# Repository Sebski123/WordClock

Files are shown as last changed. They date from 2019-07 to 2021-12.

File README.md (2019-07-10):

Wordclock
=========

Instructables: http://www.instructables.com/id/wordclock/

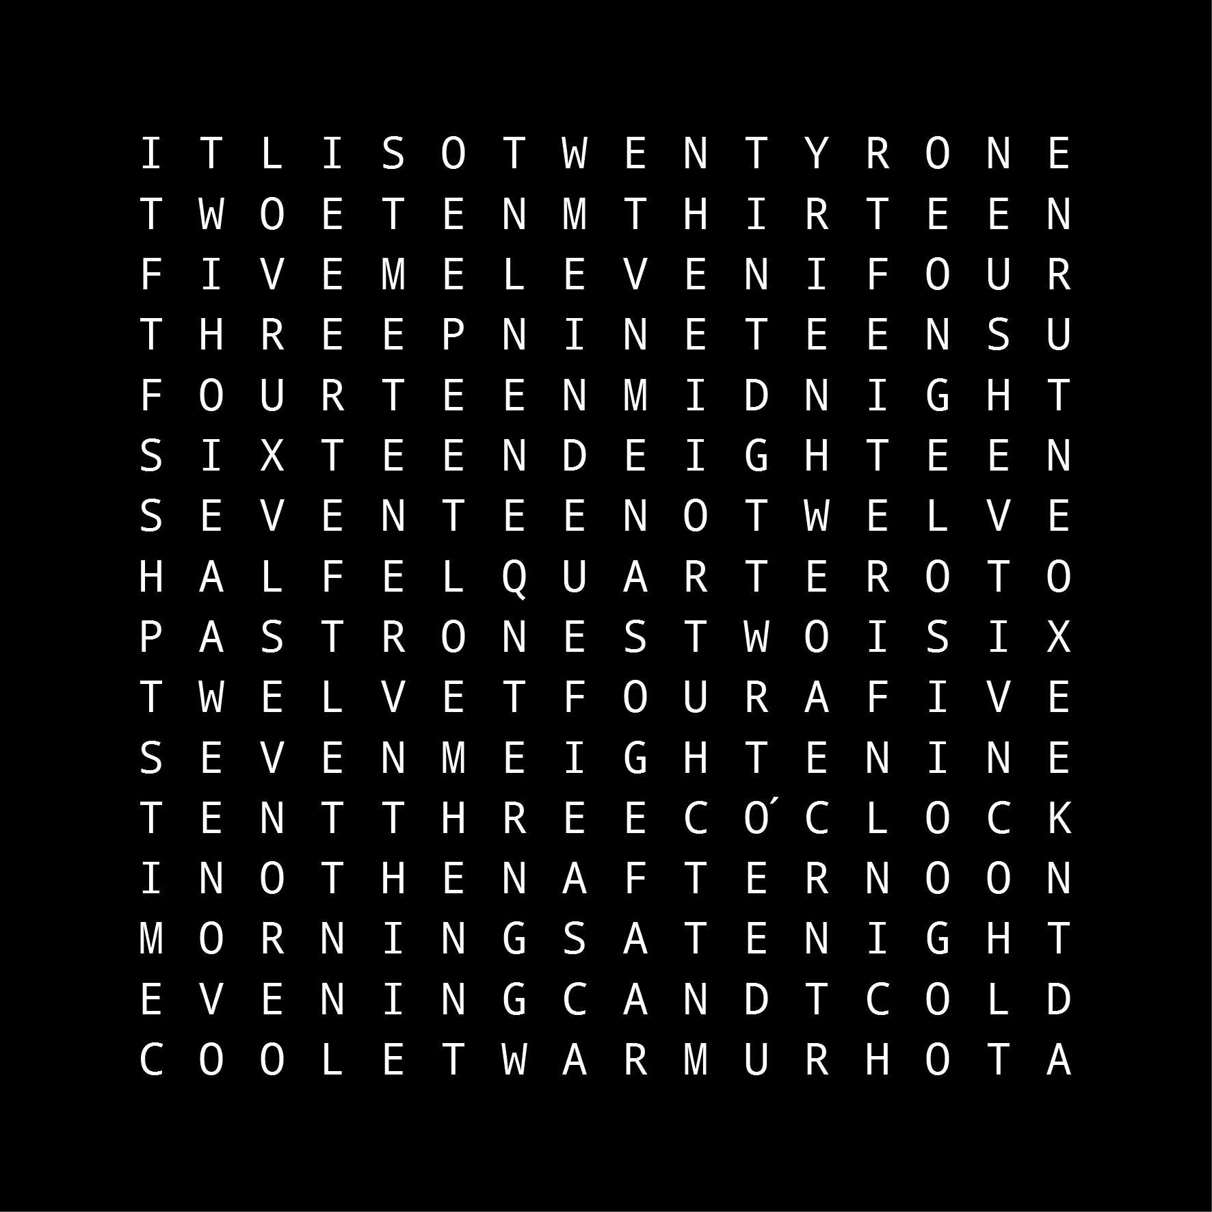
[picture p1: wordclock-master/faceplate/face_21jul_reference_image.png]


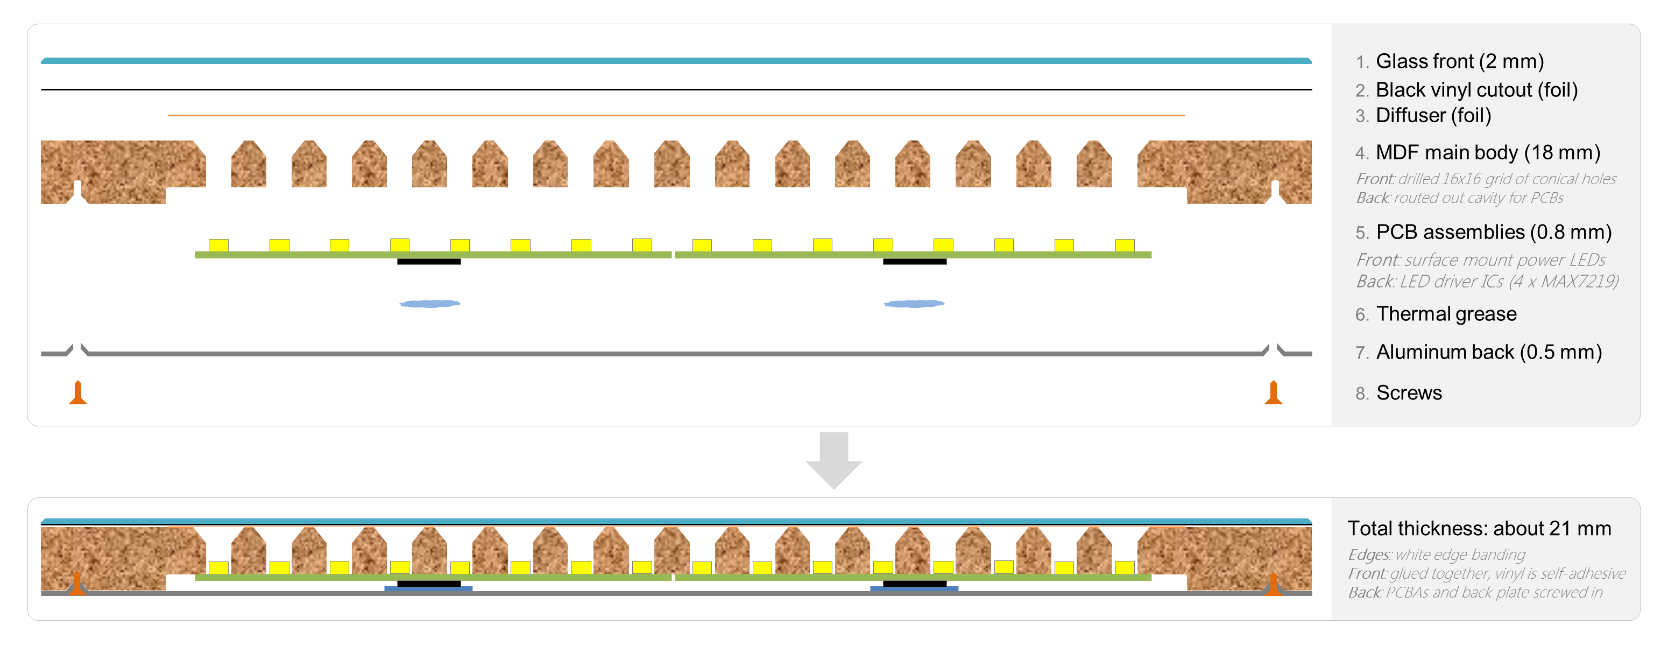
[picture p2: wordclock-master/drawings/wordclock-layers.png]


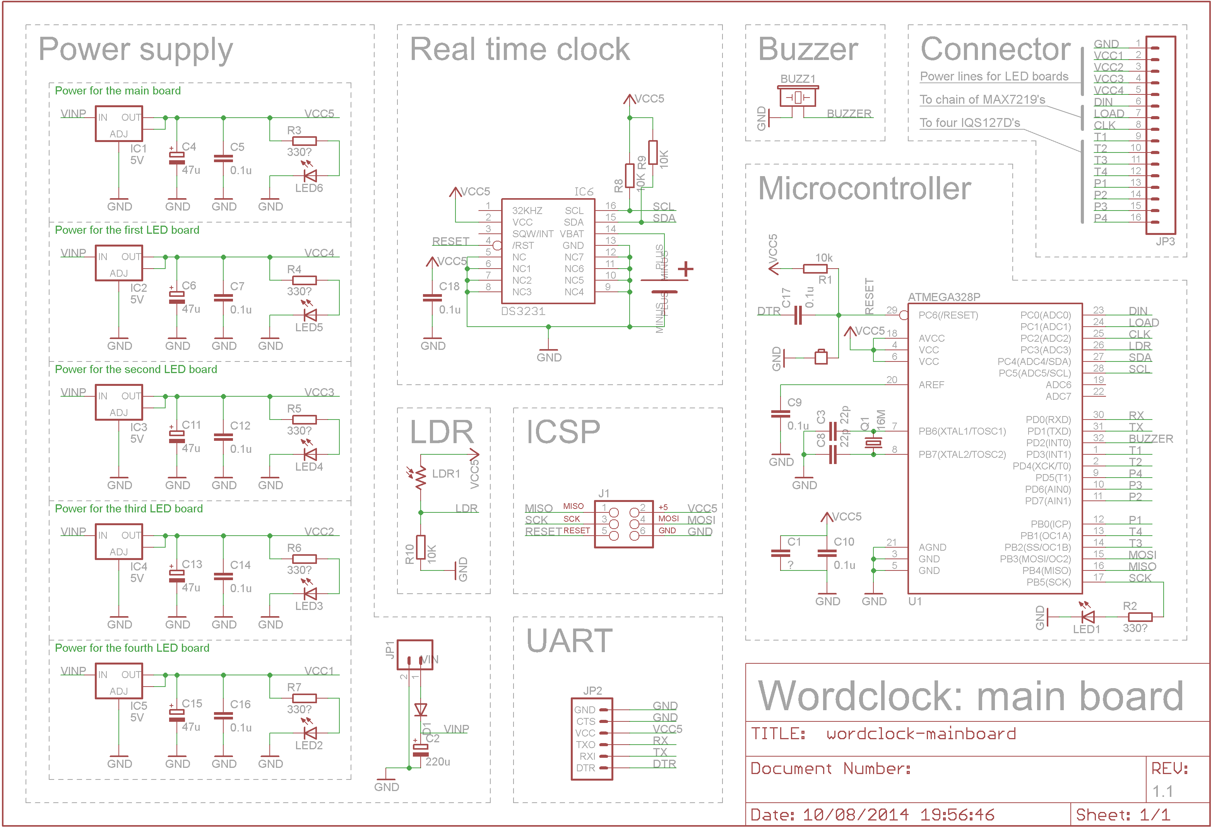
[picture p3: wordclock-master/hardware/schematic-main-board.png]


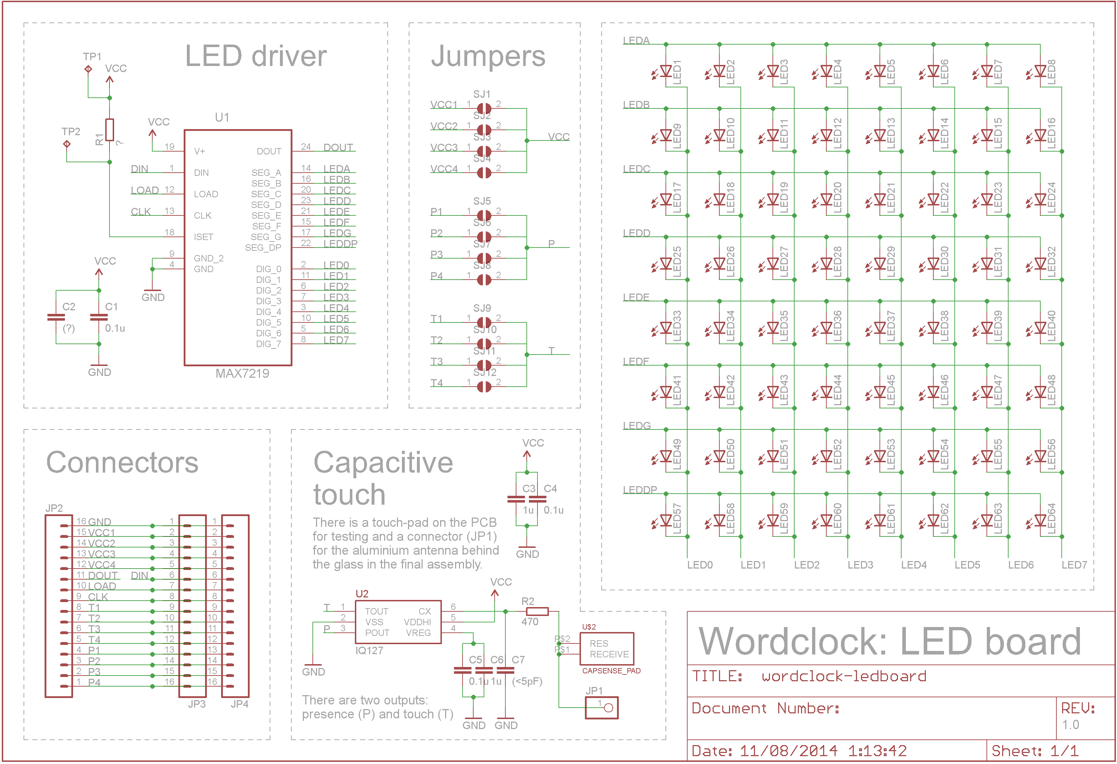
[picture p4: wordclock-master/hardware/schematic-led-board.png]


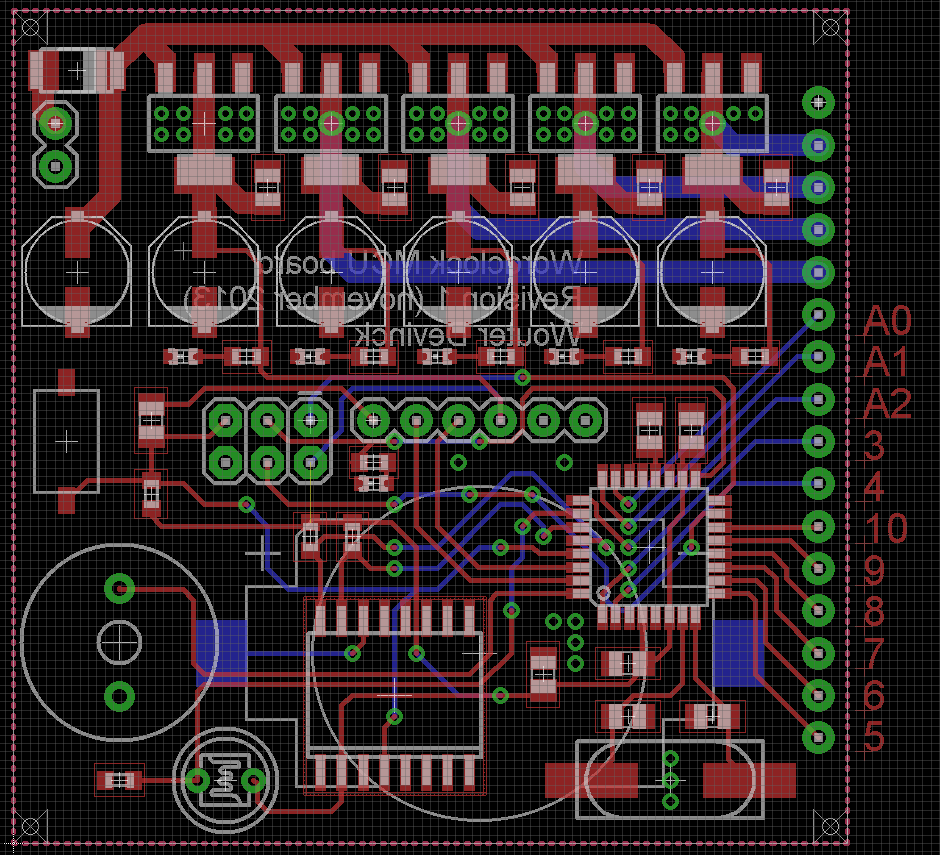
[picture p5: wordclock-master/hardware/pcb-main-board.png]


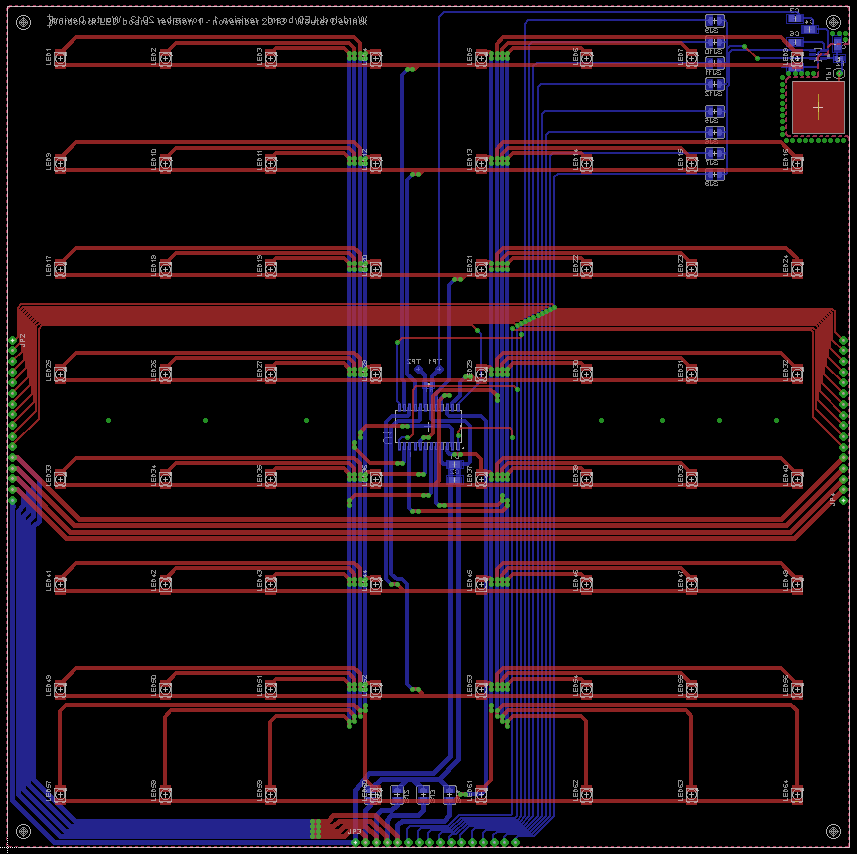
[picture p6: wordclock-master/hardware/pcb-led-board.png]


Video on YouTube (http://www.youtube.com/watch?v=86BiDWXyuwA)

<br />This work is licensed under a <a rel="license" href="http://creativecommons.org/licenses/by-nc-sa/4.0/">Creative Commons Attribution-NonCommercial-ShareAlike 4.0 International License</a>.

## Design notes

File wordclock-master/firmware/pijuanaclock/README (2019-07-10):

Pijuana wordclock
=================

This is the code for a modified version of Wordclock, made by Wouter Devinck in 2014:
http://www.instructables.com/id/Wordclock/
https://github.com/wouterdevinck/wordclock/

Our version implements a Catalan language translation of the wordclock and adds many new features, making it an amazing and multifunctional wall clock.

The hardware platform is almost identical to Wouter's project. The main difference is that we used a regular Arduino Nano and an external RTC module, instead of the custom PCB with power circuitry and Atmega328P, DS3231 chips from the original project.

The name comes from a happily newly married couple, recipient of the clock as a present.

July 2015 - September 2015
 Aleix Mercader, Antonio Camacho, Cesar August Pomerol, Enric Masdeu,
 Isabel Martínez, Jordi Aranda, Laura Mampel, Oriol Bernadó, Sergi Vaqué

License
-------
 
This work is licensed under a Creative Commons Attribution-NonCommercial-ShareAlike 4.0 International License
http://creativecommons.org/licenses/by-nc-sa/4.0/

Dependencies
------------
  * Arduino libraries                - http://arduino.cc/
  * Chronodot library (for DS3231)   - https://github.com/Stephanie-Maks/Arduino-Chronodot
  * LedControl library (for MAX7219) - http://playground.arduino.cc/Main/LedControl
  * Temp. sensor library (for DHT22) - https://github.com/adafruit/DHT-sensor-library
  * Simple Tetris Clone library      - https://github.com/ex/blocks

Modes
-----

  1.- Wordclock
  2.- Digital Clock
  3.- Temperature & Humidity
  4.- Analog Clock
  5.- Game of Life
  6.- Simon Says Game
  7.- Tetris Game
  8.- Credits

Description of files
--------------------

  pijuanaclock.ino     Main program
  brightness.cpp/.h    Brightness autoadjustment
  character.cpp/.h     Character (digit) definitions
  credits.cpp/.h       Ending Credits 
  display.cpp/.h       Display & LED functions
  life.cpp/.h          Game of Life 
  serial.cpp/.h        Serial port setup menu
  simon.cpp/.h         Simon Says game 
  temphum.cpp/.h       Temperature & Humidity display
  tetris.cpp/.h        Tetris game
  time.cpp/.h          Wordclock, digital clock
  timeanalog.cpp/.h    Analog clock 
  touchbuttons.cpp/.h  Touch buttons, mode switching
  
  Third party libraries:
    
  Chronodot.cpp/.h       Chronodot library (for DS3231) 
  DHT.cpp/.h             Temperature sensor library (for DHT22)
  LedControl.cpp/.h      LedControl library (for MAX7219)
  stc.cpp/.h/platform.h  Simple Tetris Clone library
  pitches.h              Note frequencies from the Arduino webpage

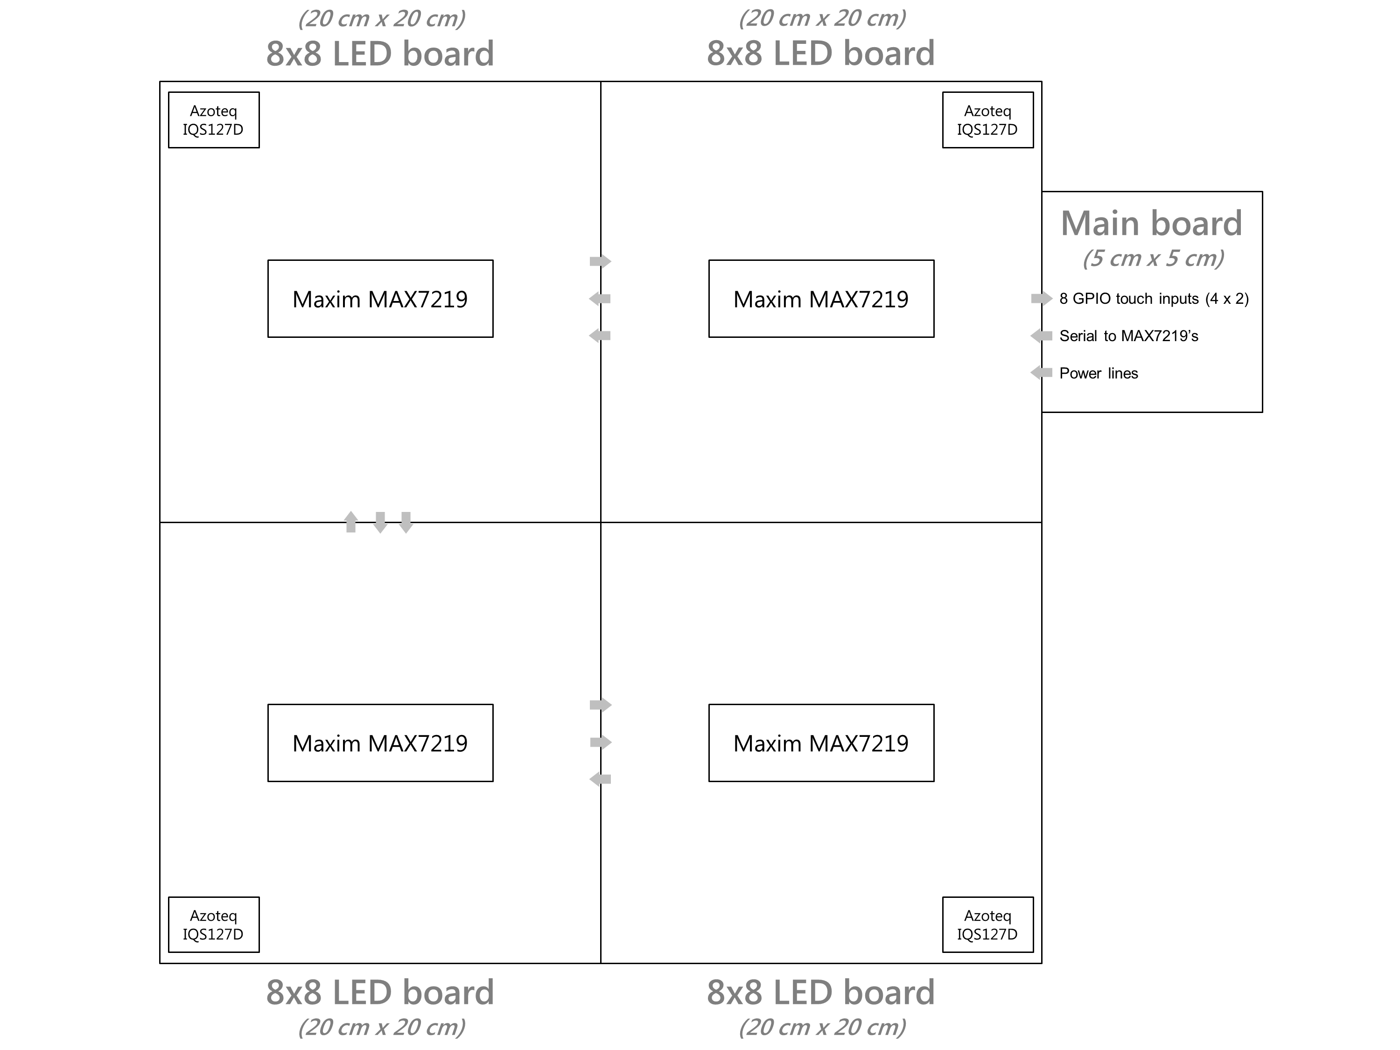
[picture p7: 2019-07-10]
wordclock-master/drawings/pcbs.png

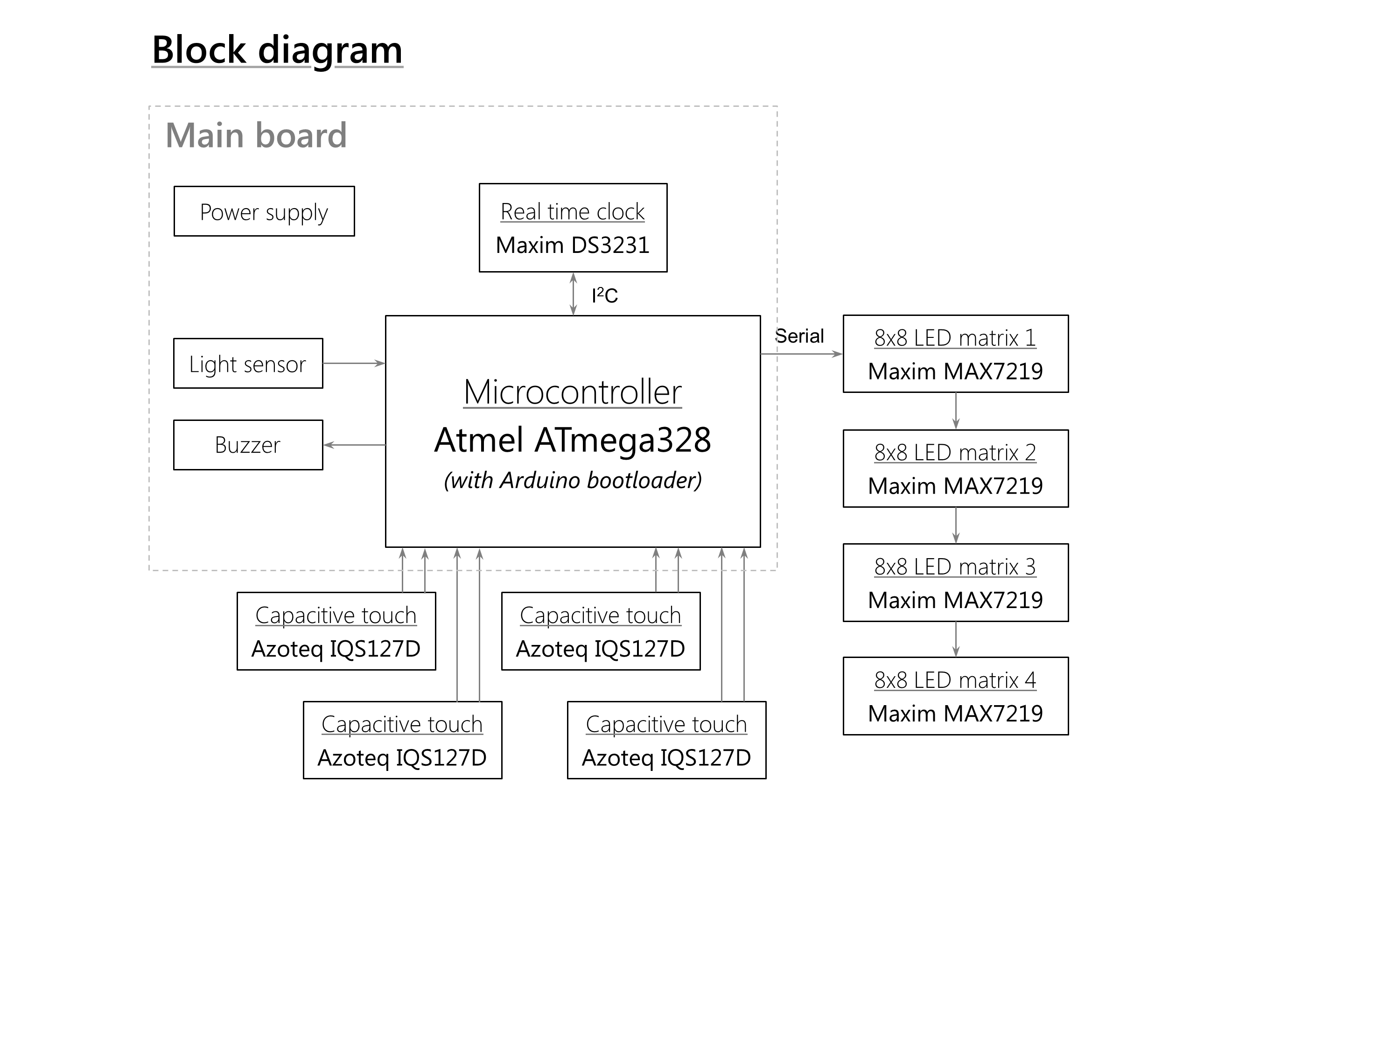
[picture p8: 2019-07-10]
wordclock-master/drawings/blockdiagram-bis.png

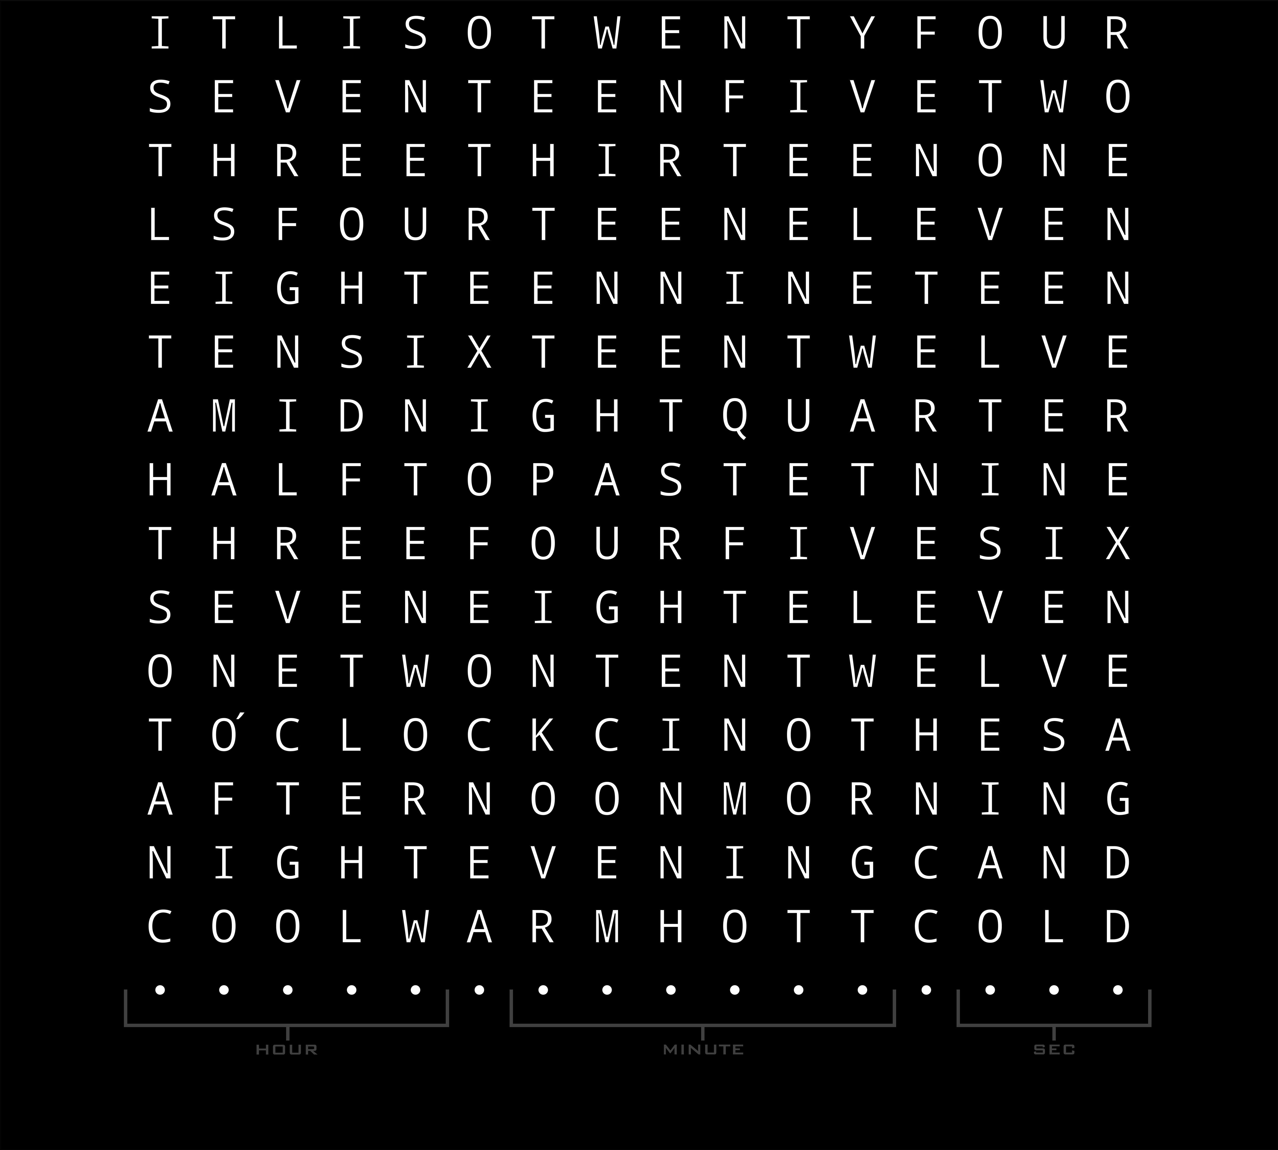
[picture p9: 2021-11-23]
wordclock-master/faceplate/face_07nov2.png

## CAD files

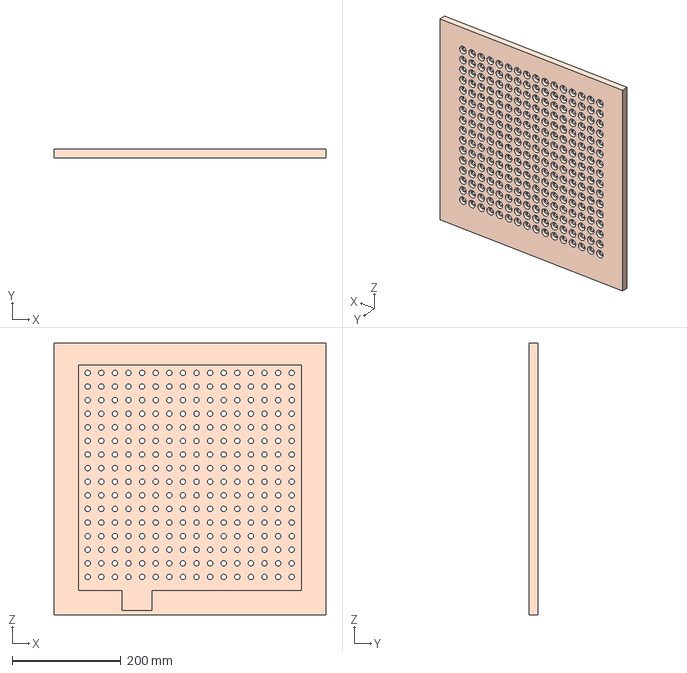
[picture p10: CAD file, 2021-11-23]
UR.FCStd
500.0 x 16.0 x 500.0 mm

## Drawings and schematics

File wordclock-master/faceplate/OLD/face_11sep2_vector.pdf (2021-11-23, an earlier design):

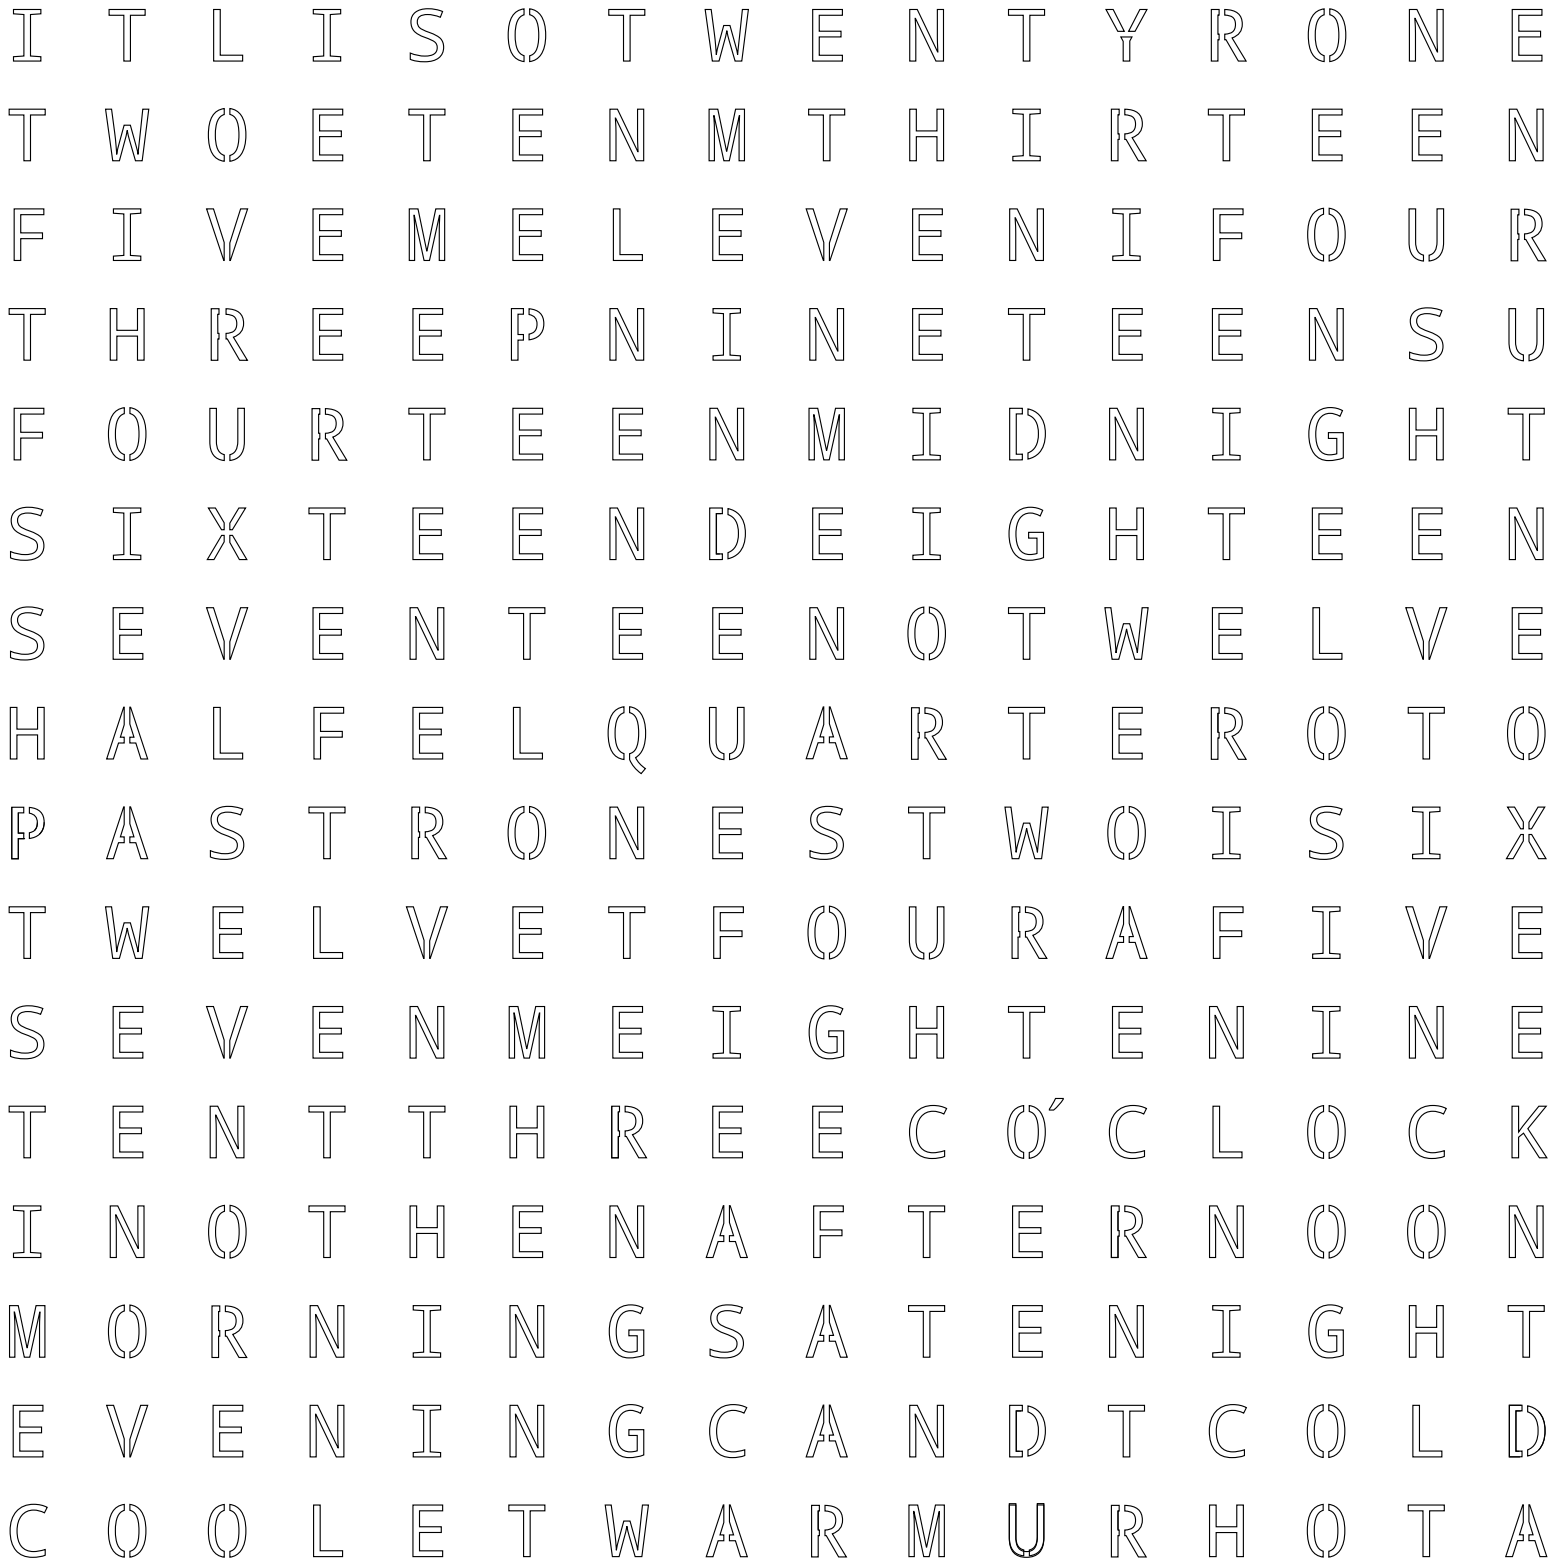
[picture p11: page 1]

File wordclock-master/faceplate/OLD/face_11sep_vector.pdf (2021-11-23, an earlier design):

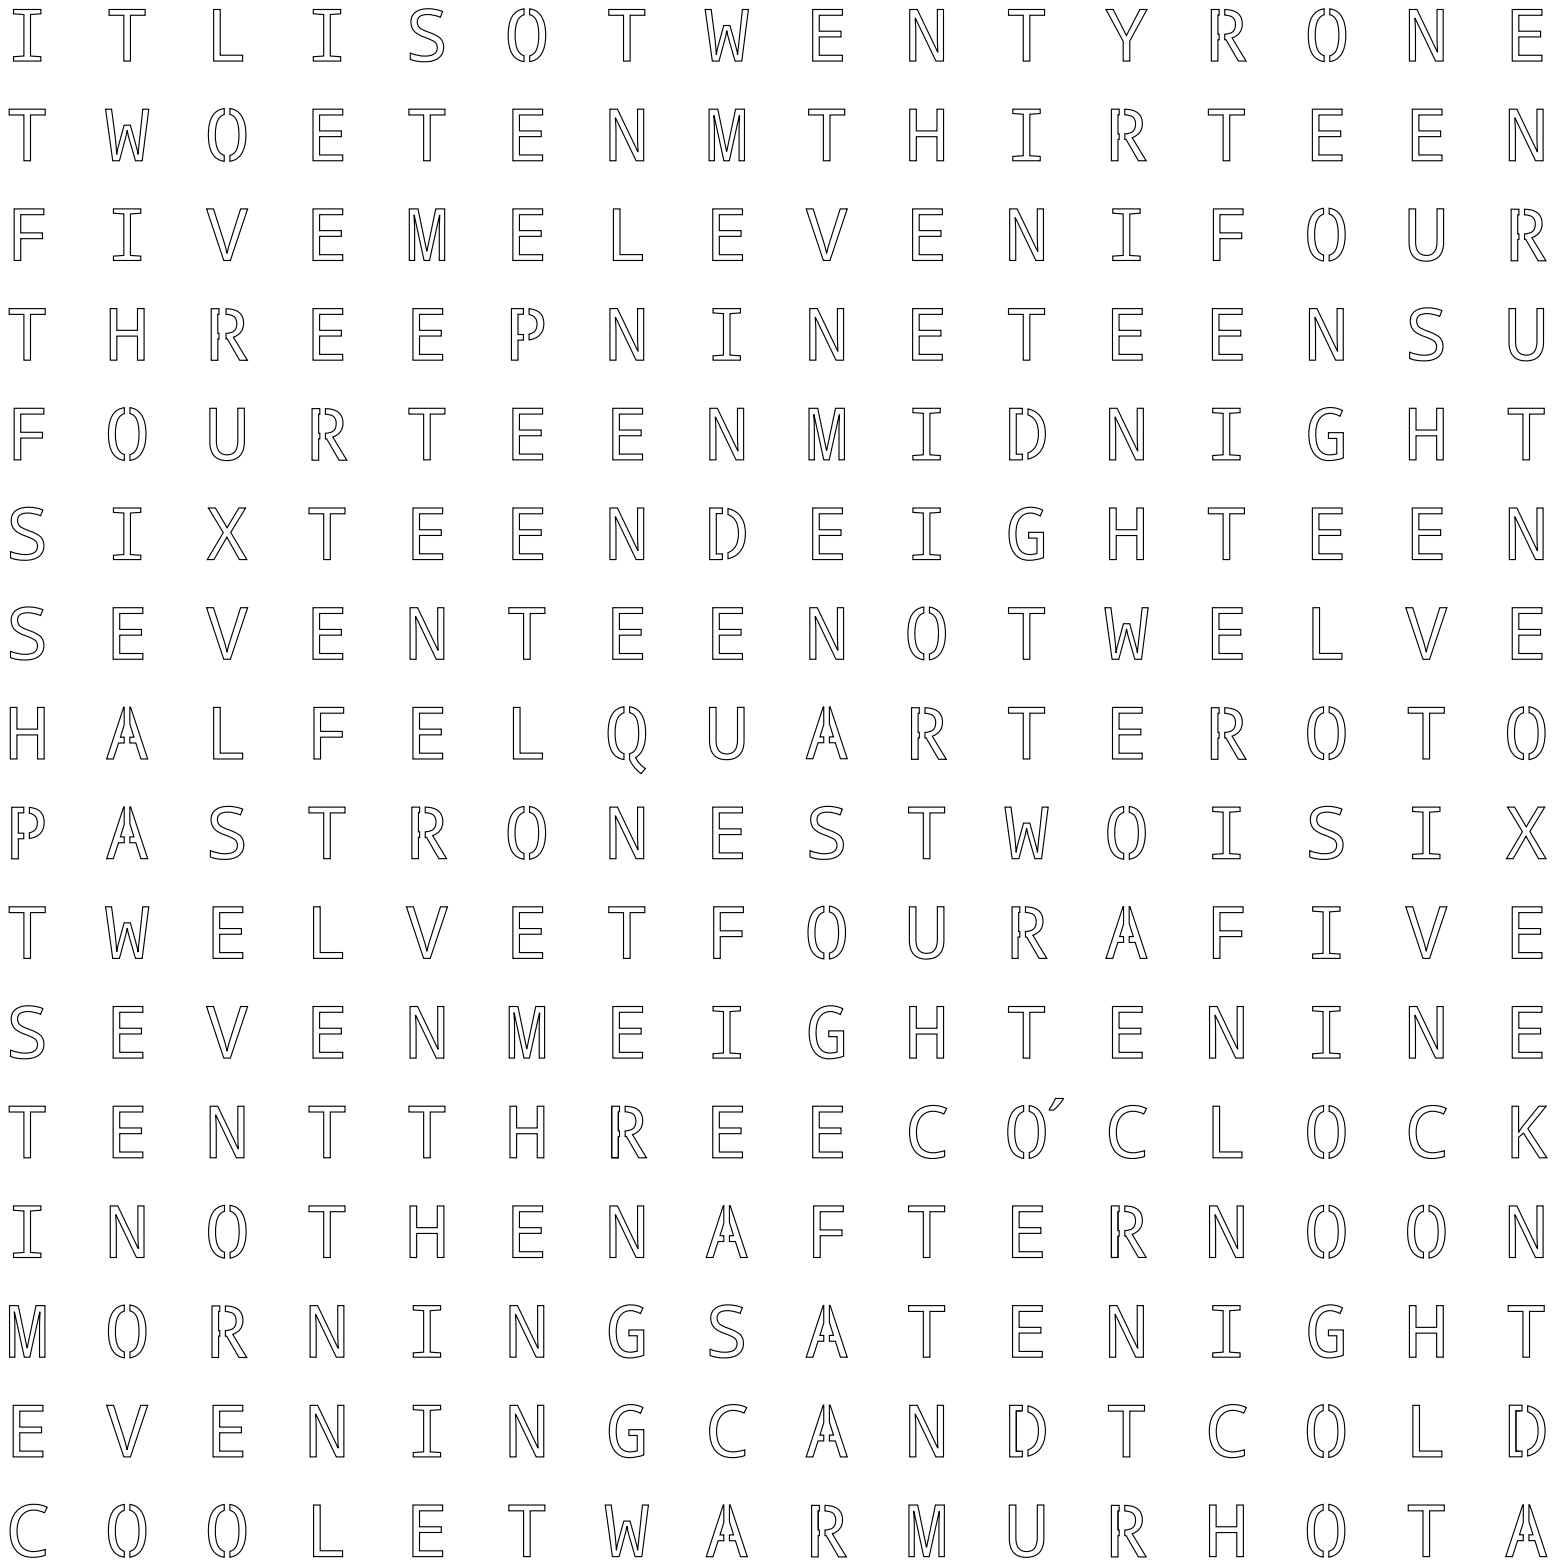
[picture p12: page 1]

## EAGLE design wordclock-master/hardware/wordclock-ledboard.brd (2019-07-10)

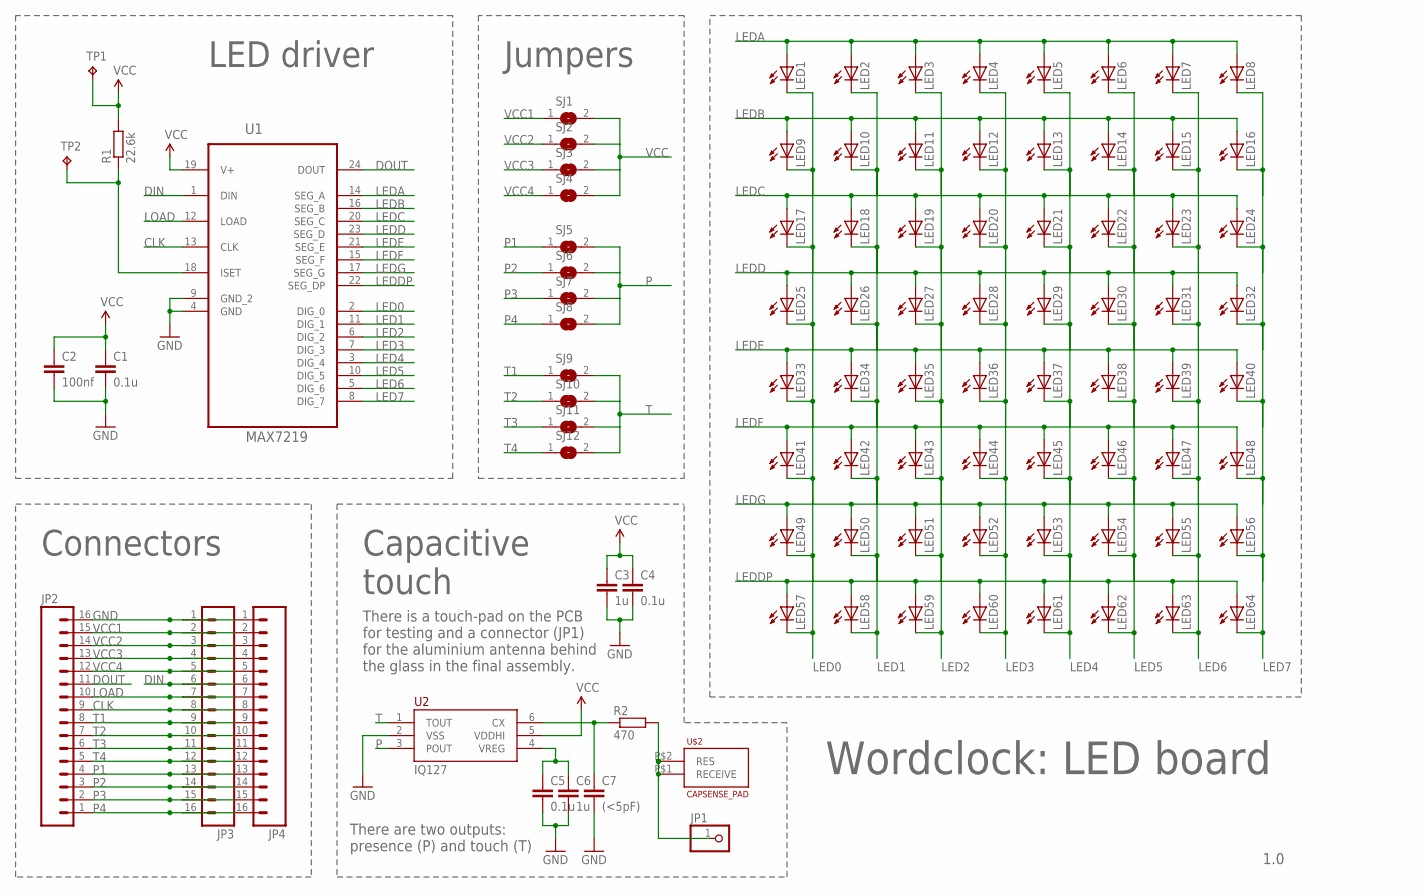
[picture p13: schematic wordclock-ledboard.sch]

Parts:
C1, C4, C5: 0.1u; C0805
C2: 100nf; C0805
C3, C6: 1u; C0805
C7: (<5pF); C0805
JP1: PINHD-1X1; 1X01
JP2, JP3, JP4: M161X16_NO_SILK; 1X16_NO_SILK
LED1, LED2, LED3, LED4, LED5, LED6, LED7, LED8, LED9, LED10, LED11, LED12, LED13, LED14, LED15, LED16, LED17, LED18, LED19, LED20, LED21, LED22, LED23, LED24, LED25, LED26, LED27, LED28, LED29, LED30, LED31, LED32, LED33, LED34, LED35, LED36, LED37, LED38, LED39, LED40, LED41, LED42, LED43, LED44, LED45, LED46, LED47, LED48, LED49, LED50, LED51, LED52, LED53, LED54, LED55, LED56, LED57, LED58, LED59, LED60, LED61, LED62, LED63, LED64: LEDKA-3528ASYC; KA-3528ASYC
R1: 22.6k; R0603
R2: 470; R0603
SJ1, SJ2, SJ3, SJ4, SJ5, SJ6, SJ7, SJ8, SJ9, SJ10, SJ11, SJ12: SJW
TP1, TP2: TPTP20R; TP20R
U1: MAX7219; SOIC127P1032X265-24N
U2: IQ127; TSOT-23-6
U$2: CAPSENSE_PAD

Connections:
C6: C5.1, C6.1, U2.4 (VREG)
CLK: JP2.9, JP3.8, JP4.8, U1.13 (CLK)
DIN: JP3.6, JP4.6, U1.1 (DIN)
DOUT: JP2.11, U1.24 (DOUT)
GND: C1.2, C2.2, C3.2, C4.2, C5.2, C6.2, C7.2, JP2.16, JP3.1, JP4.1, U1.4 (GND), U1.9 (GND_2), U2.2 (VSS)
LED0: LED1.C, LED9.C, LED17.C, LED25.C, LED33.C, LED41.C, LED49.C, LED57.C, U1.2 (DIG_0)
LED1: LED2.C, LED10.C, LED18.C, LED26.C, LED34.C, LED42.C, LED50.C, LED58.C, U1.11 (DIG_1)
LED2: LED3.C, LED11.C, LED19.C, LED27.C, LED35.C, LED43.C, LED51.C, LED59.C, U1.6 (DIG_2)
LED3: LED4.C, LED12.C, LED20.C, LED28.C, LED36.C, LED44.C, LED52.C, LED60.C, U1.7 (DIG_3)
LED4: LED5.C, LED13.C, LED21.C, LED29.C, LED37.C, LED45.C, LED53.C, LED61.C, U1.3 (DIG_4)
LED5: LED6.C, LED14.C, LED22.C, LED30.C, LED38.C, LED46.C, LED54.C, LED62.C, U1.10 (DIG_5)
LED6: LED7.C, LED15.C, LED23.C, LED31.C, LED39.C, LED47.C, LED55.C, LED63.C, U1.5 (DIG_6)
LED7: LED8.C, LED16.C, LED24.C, LED32.C, LED40.C, LED48.C, LED56.C, LED64.C, U1.8 (DIG_7)
LEDA: LED1.A, LED2.A, LED3.A, LED4.A, LED5.A, LED6.A, LED7.A, LED8.A, U1.14 (SEG_A)
LEDB: LED9.A, LED10.A, LED11.A, LED12.A, LED13.A, LED14.A, LED15.A, LED16.A, U1.16 (SEG_B)
LEDC: LED17.A, LED18.A, LED19.A, LED20.A, LED21.A, LED22.A, LED23.A, LED24.A, U1.20 (SEG_C)
LEDD: LED25.A, LED26.A, LED27.A, LED28.A, LED29.A, LED30.A, LED31.A, LED32.A, U1.23 (SEG_D)
LEDDP: LED57.A, LED58.A, LED59.A, LED60.A, LED61.A, LED62.A, LED63.A, LED64.A, U1.22 (SEG_DP)
LEDE: LED33.A, LED34.A, LED35.A, LED36.A, LED37.A, LED38.A, LED39.A, LED40.A, U1.21 (SEG_E)
LEDF: LED41.A, LED42.A, LED43.A, LED44.A, LED45.A, LED46.A, LED47.A, LED48.A, U1.15 (SEG_F)
LEDG: LED49.A, LED50.A, LED51.A, LED52.A, LED53.A, LED54.A, LED55.A, LED56.A, U1.17 (SEG_G)
LOAD: JP2.10, JP3.7, JP4.7, U1.12 (LOAD)
unnamed: JP1.1, R2.2, U$2.P$1 (RECEIVE), U$2.P$2 (RES)
unnamed: R1.1, TP2.TP, U1.18 (ISET)
unnamed: C7.1, R2.1, U2.6 (CX)
P: SJ5.2, SJ6.2, SJ7.2, SJ8.2, U2.3 (POUT)
P1: JP2.4, JP3.13, JP4.13, SJ5.1
P2: JP2.3, JP3.14, JP4.14, SJ6.1
P3: JP2.2, JP3.15, JP4.15, SJ7.1
P4: JP2.1, JP3.16, JP4.16, SJ8.1
T: SJ9.2, SJ10.2, SJ11.2, SJ12.2, U2.1 (TOUT)
T1: JP2.8, JP3.9, JP4.9, SJ9.1
T2: JP2.7, JP3.10, JP4.10, SJ10.1
T3: JP2.6, JP3.11, JP4.11, SJ11.1
T4: JP2.5, JP3.12, JP4.12, SJ12.1
VCC: C1.1, C2.1, C3.1, C4.1, R1.2, SJ1.2, SJ2.2, SJ3.2, SJ4.2, TP1.TP, U1.19 (V+), U2.5 (VDDHI)
VCC1: JP2.15, JP3.2, JP4.2, SJ1.1
VCC2: JP2.14, JP3.3, JP4.3, SJ2.1
VCC3: JP2.13, JP3.4, JP4.4, SJ3.1
VCC4: JP2.12, JP3.5, JP4.5, SJ4.1

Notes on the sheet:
Wordclock: LED board
1.0
LED driver
Jumpers
IQ127
Capacitive touch
Connectors
There is a touch-pad on the PCB for testing and a connector (JP1) for the aluminium antenna behind the glass in the final assembly.
There are two outputs: presence (P) and touch (T)

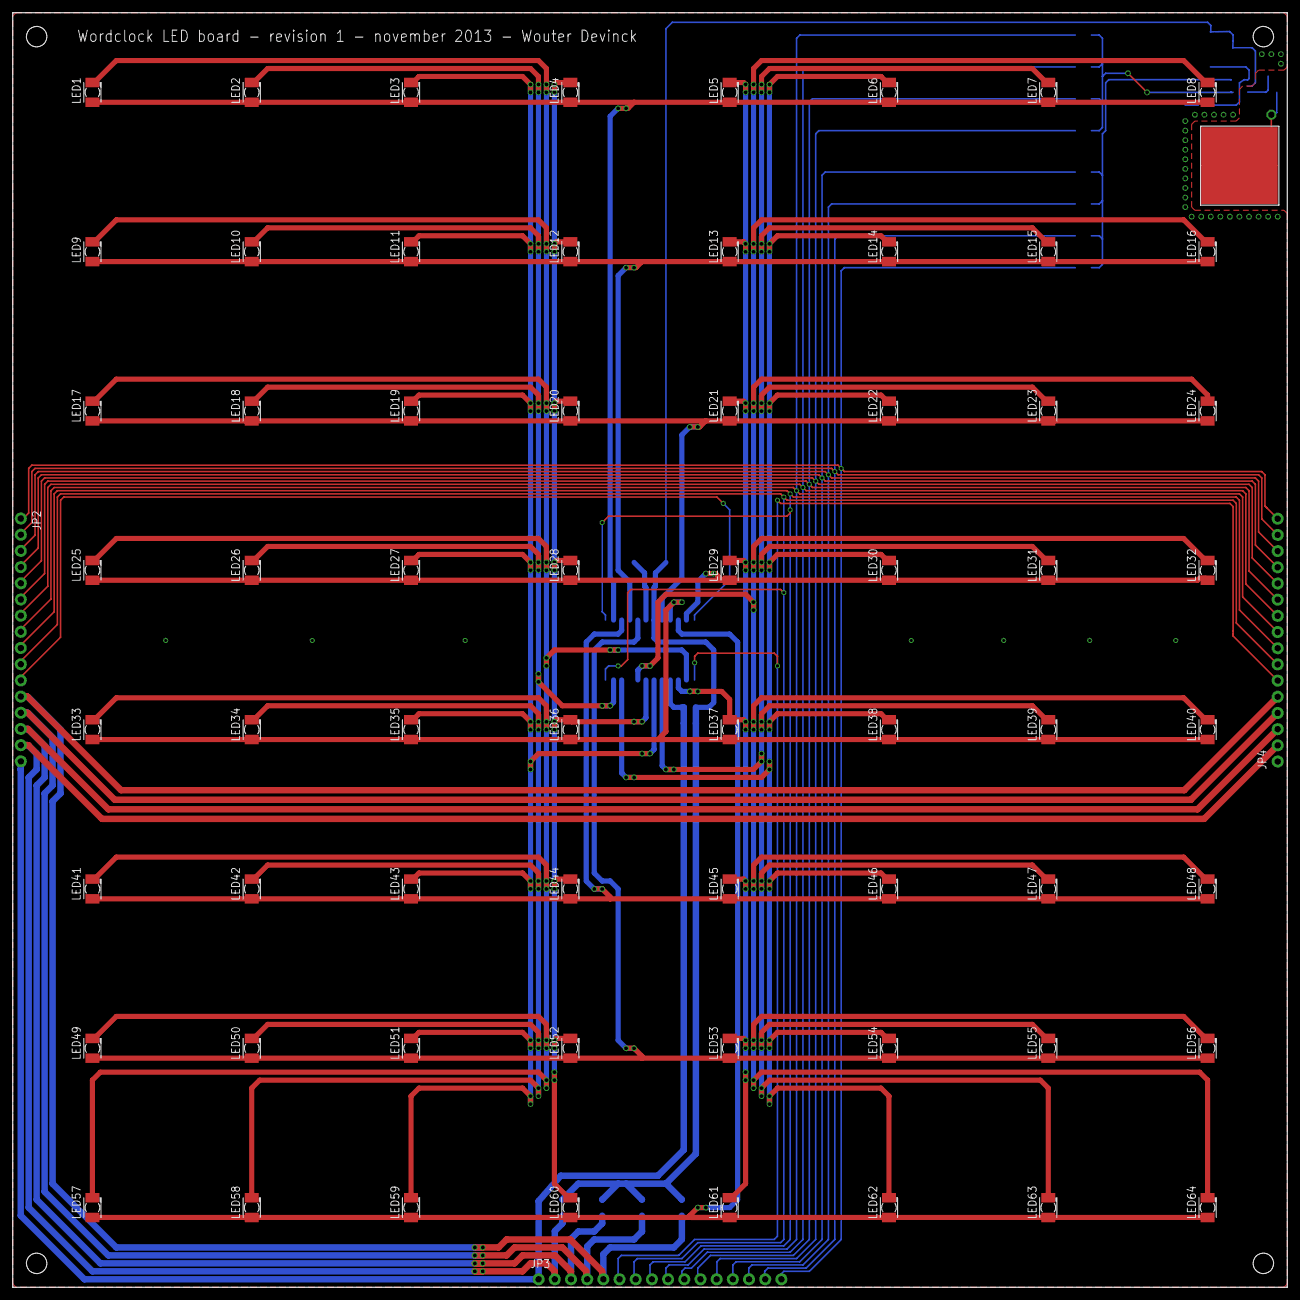
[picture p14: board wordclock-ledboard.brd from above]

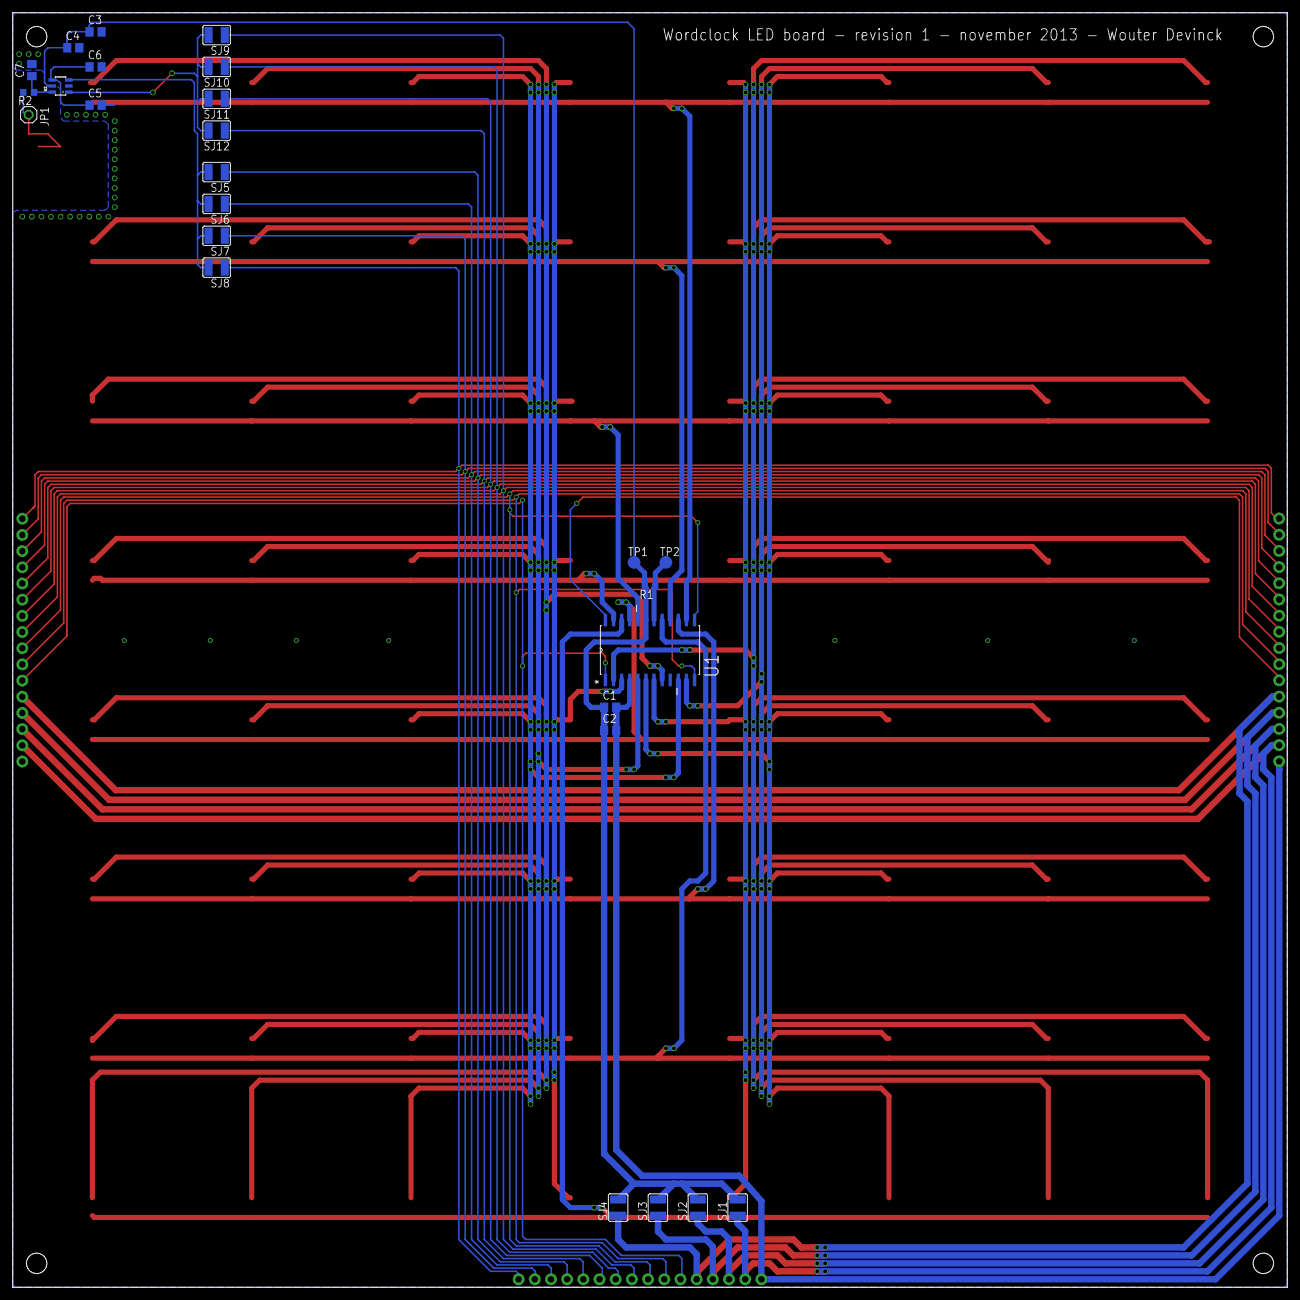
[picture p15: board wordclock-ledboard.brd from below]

Board: 4 copper layers, 200.0 x 200.0 mm, 94 parts (26 on the bottom side), 40 nets.

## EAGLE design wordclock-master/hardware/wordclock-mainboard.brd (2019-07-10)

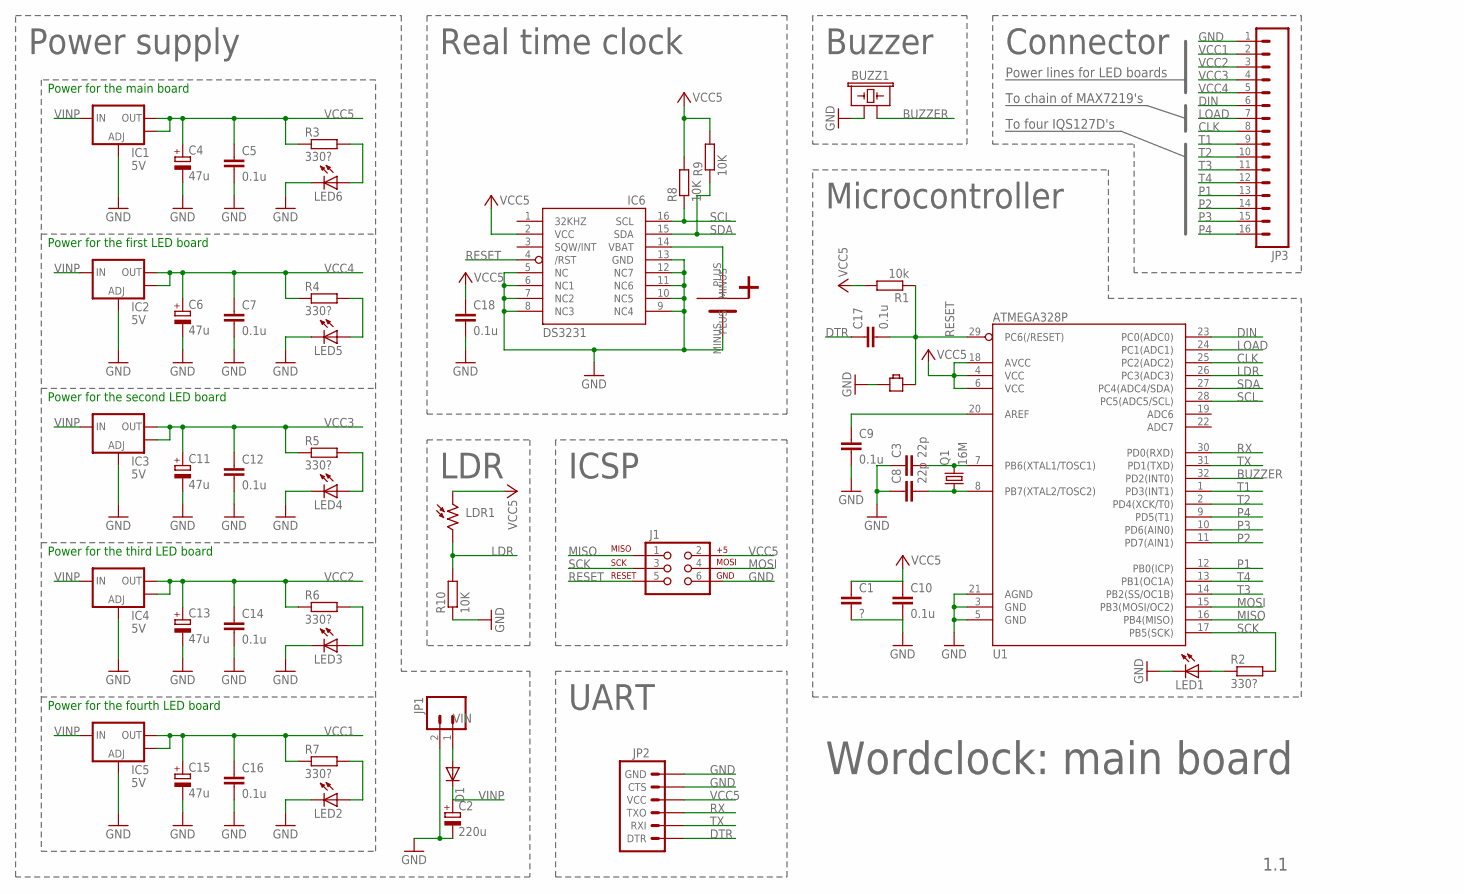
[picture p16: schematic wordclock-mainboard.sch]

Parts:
BUZZ1: BUZZERPTH; BUZZER-12MM
C1: ?; C0805
C2: 220u; PANASONIC_D
C3, C8: 22p; C0805
C4, C6, C11, C13, C15: 47u; PANASONIC_D
C5, C7, C9, C10, C12, C14, C16, C17, C18: 0.1u; C0805
D1: DIODE-DO-214AC; DO-214AC
IC1, IC2, IC3, IC4, IC5: 5V; SOT223
IC6: DS3231/SO; SO16W
J1: AVR_SPI_PRG_6PTH; 2X3
JP1: M02PTH; 1X02
JP2: ARDUINO_SERIAL_PROGRAMPTH; 1X06
JP3: M161X16_NO_SILK; 1X16_NO_SILK
LDR1: A1050_09; T0-46-A10XX
LED1, LED2, LED3, LED4, LED5, LED6: LEDCHIPLED_0603; CHIPLED_0603
Q1: 16M; CSM-7X-DU
R1: 10k; R0603
R2, R3, R4, R5, R6, R7: 330?; R0603
R8, R9, R10: 10K; R0603
RESET: BUTTON-SMD-2P; BUTTON_2P_SMD
U1: ATMEGA328P; TQFP32-08
U$1: SMD-CR2032; SMD-BATT

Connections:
BUZZER: BUZZ1.- (2), U1.32 (PD2(INT0))
CLK: JP3.8, U1.25 (PC2(ADC2))
DIN: JP3.6, U1.23 (PC0(ADC0))
DTR: C17.1, JP2.1 (DTR)
GND: BUZZ1.+ (1), C1.2, C2.-, C3.1, C4.-, C5.2, C6.-, C7.2, C8.1, C9.2, C10.2, C11.-, C12.2, C13.-, C14.2, C15.-, C16.2, C18.2, IC1.1 (ADJ), IC2.1 (ADJ), IC3.1 (ADJ), IC4.1 (ADJ), IC5.1 (ADJ), IC6.5 (NC), IC6.6 (NC1), IC6.7 (NC2), IC6.8 (NC3), IC6.9 (NC4), IC6.10 (NC5), IC6.11 (NC6), IC6.12 (NC7), IC6.13 (GND), J1.6, JP1.2, JP2.5 (CTS), JP2.6 (GND), JP3.1, LED1.C, LED2.C, LED3.C, LED4.C, LED5.C, LED6.C, R10.1, RESET.1, U1.3 (GND), U1.5 (GND), U1.21 (AGND), U$1.MINUS
LDR: LDR1.2, R10.2, U1.26 (PC3(ADC3))
LOAD: JP3.7, U1.24 (PC1(ADC1))
MISO: J1.1, U1.16 (PB4(MISO))
MOSI: J1.4, U1.15 (PB3(MOSI/OC2))
unnamed: C3.2, Q1.2, U1.7 (PB6(XTAL1/TOSC1))
unnamed: C8.2, Q1.1, U1.8 (PB7(XTAL2/TOSC2))
unnamed: LED1.A, R2.1
unnamed: LED2.A, R7.2
unnamed: C9.1, U1.20 (AREF)
unnamed: LED3.A, R6.2
unnamed: LED4.A, R5.2
unnamed: LED6.A, R3.2
unnamed: LED5.A, R4.2
unnamed: IC6.14 (VBAT), U$1.PLUS
P1: JP3.13, U1.12 (PB0(ICP))
P2: JP3.14, U1.11 (PD7(AIN1))
P3: JP3.15, U1.10 (PD6(AIN0))
P4: JP3.16, U1.9 (PD5(T1))
RESET: C17.2, IC6.4 (/RST), J1.5, R1.1, RESET.P$2, U1.29 (PC6(/RESET))
RX: JP2.3 (TXO), U1.30 (PD0(RXD))
SCK: J1.3, R2.2, U1.17 (PB5(SCK))
SCL: IC6.16 (SCL), R8.1, U1.28 (PC5(ADC5/SCL))
SDA: IC6.15 (SDA), R9.1, U1.27 (PC4(ADC4/SDA))
T1: JP3.9, U1.1 (PD3(INT1))
T2: JP3.10, U1.2 (PD4(XCK/T0))
T3: JP3.11, U1.14 (PB2(SS/OC1B))
T4: JP3.12, U1.13 (PB1(OC1A))
TX: JP2.2 (RXI), U1.31 (PD1(TXD))
VCC1: C15.+, C16.1, IC5.2 (OUT), IC5.4 (OUT), JP3.2, R7.1
VCC2: C13.+, C14.1, IC4.2 (OUT), IC4.4 (OUT), JP3.3, R6.1
VCC3: C11.+, C12.1, IC3.2 (OUT), IC3.4 (OUT), JP3.4, R5.1
VCC4: C6.+, C7.1, IC2.2 (OUT), IC2.4 (OUT), JP3.5, R4.1
VCC5: C1.1, C4.+, C5.1, C10.1, C18.1, IC1.2 (OUT), IC1.4 (OUT), IC6.2 (VCC), J1.2, JP2.4 (VCC), LDR1.1, R1.2, R3.1, R8.2, R9.2, U1.4 (VCC), U1.6 (VCC), U1.18 (AVCC)
VIN: D1.A, JP1.1
VINP: C2.+, D1.C, IC1.3 (IN), IC2.3 (IN), IC3.3 (IN), IC4.3 (IN), IC5.3 (IN)

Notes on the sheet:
Power supply
Wordclock: main board
1.1
Microcontroller
Power for the main board
ICSP
Power for the first LED board
Power for the second LED board
Power for the third LED board
Power for the fourth LED board
UART
Real time clock
LDR
Buzzer
Connector
Power lines for LED boards
To chain of MAX7219's
To four IQS127D's

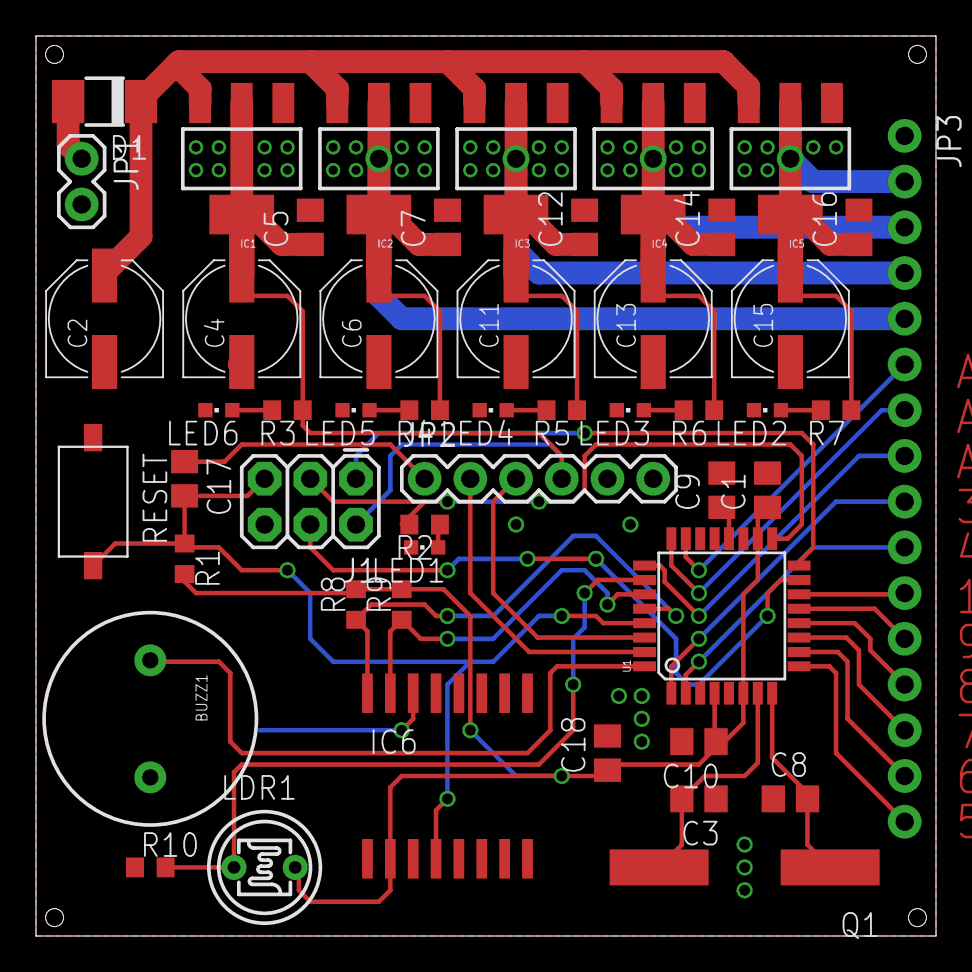
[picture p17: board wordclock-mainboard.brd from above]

Board: 4 copper layers, 50.0 x 50.0 mm, 51 parts (1 on the bottom side), 40 nets.

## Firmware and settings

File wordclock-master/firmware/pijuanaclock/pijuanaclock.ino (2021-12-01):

// Pijuana Wordclock Project firmware
// ==================
// Based on the Wordclock by Wouter Devinck (August 2014)
// Translation and extension of that project, adding Catalan hours format and many new modes.
// July 2015 - September 2015
 
// Aleix Mercader, Antonio Camacho, Cesar August Pomerol, Enric Masdeu,
// Isabel Martínez, Jordi Aranda, Laura Mampel, Oriol Bernadó, Sergi Vaqué

// Dependencies:
//  * Arduino libraries                - http://arduino.cc/
//  * Chronodot library (for DS3231)   - https://github.com/Stephanie-Maks/Arduino-Chronodot
//  * LedControl library (for MAX7219) - http://playground.arduino.cc/Main/LedControl
//  * Temp. sensor library (for DHT22) - https://github.com/adafruit/DHT-sensor-library
//  * Simple Tetris Clone library      - https://github.com/ex/blocks

/* Hardware block diagram:

              +-----------------+
              | Real time clock |
              | Maxim DS3231    |
              +--------+--------+
                       |I2C
         +-------------+-------------+
+-----+  |                           |   +------------------+
|DHT22+--|                           +---+ 8x8 LED matrix 1 |
+-----+  |                           |   | Maxim MAX7219    |
         |                           |   +---------+--------+
+---+    |      Microcontroller      |             |
|LDR+----+      Atmel ATMEGA328      |   +---------+--------+
+---+    |      (with Arduino        |   | 8x8 LED matrix 2 |
         |       bootloader)         |   | Maxim MAX7219    |
+------+ |                           |   +---------+--------+
|Buzzer+-+                           |             |
+------+ |                           |   +---------+--------+
         +-++----++---------++----++-+   | 8x8 LED matrix 3 |
           ||    ||         ||    ||     | Maxim MAX7219    |
    +------++-+  ||  +------++-+  ||     +---------+--------+
    | Azoteq  |  ||  | Azoteq  |  ||               |
    | IQS127D |  ||  | IQS127D |  ||     +---------+--------+
    +---------+  ||  +---------+  ||     | 8x8 LED matrix 4 |
                 ||               ||     | Maxim MAX7219    |
          +------++-+      +------++-+   +------------------+
          | Azoteq  |      | Azoteq  |
          | IQS127D |      | IQS127D |
          +---------+      +---------+

(created using http://asciiflow.com/) */


// Includes
#include <EEPROM.h>
#include <Wire.h>

#include "animation.h"
#include "brightness.h"
#include "character.h"
#include "display.h"
#include "life.h"
#include "serial.h"
#include "time.h"
#include "timeanalog.h"
#include "touchbuttons.h"

void setup() {

  // Debug info
  Serial.begin(9600);
  Serial.println(F("Wordclock is booting"));
  
  // Initiate the LED drivers
  // Brightness is set to max by default
  Serial.println(F("Init LED drivers"));
  initDisplay();

  // Initiate the Real Time Clock
  Serial.println(F("Init RTC"));
  initRTC();

  // Initiate the capacitive touch inputs
  Serial.println(F("Init touch sensor"));
  initTouch();

  // Read settings from EEPROM
  Serial.println(F("Read settings"));
  byte initial = EEPROM.read(EEPROM_INITIAL_MODE);
  boolean showBoot = EEPROM.read(EEPROM_SHOW_BOOT);

  setBrightness(15);

  Serial.println(F("Done. Hello!"));

  // Show serial menu
  printMenu();

  // Go to initial mode
  goToMode(initial);
}


void loop() {

  // Camacho's state machine
  //getInput();
  readTouch();
  stateManager();
  //setOutput();
}



void stateManager()
{
  static byte prevDisplayMode = -1;
  
  unsigned long now = millis();

  boolean modeChanged = prevDisplayMode != displayMode;
  prevDisplayMode = displayMode;

  // Run state-dependent code
  switch (displayMode)
  {
    case MODE_WORD_CLOCK:
    case MODE_DIGITAL_CLOCK:

      timeManager(now, modeChanged);
      break;

    case MODE_GAME_OF_LIFE:
    
      gameOfLifeManager(now, modeChanged);
      break;

    case MODE_ANIMATION:
    
      animationManager(now, modeChanged);
      break;

    default:
      break;
  }

  // State-independent code
  brightnessManager(now);
  serialManager(now);
}

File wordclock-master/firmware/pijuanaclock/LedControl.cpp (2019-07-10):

/*
 *    LedControl.cpp - A library for controling Leds with a MAX7219/MAX7221
 *    Copyright (c) 2007 Eberhard Fahle
 * 
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
 *    This permission notice shall be included in all copies or 
 *    substantial portions of the Software.
 * 
 *    THE SOFTWARE IS PROVIDED "AS IS", WITHOUT WARRANTY OF ANY KIND,
 *    EXPRESS OR IMPLIED, INCLUDING BUT NOT LIMITED TO THE WARRANTIES
 *    OF MERCHANTABILITY, FITNESS FOR A PARTICULAR PURPOSE AND
 *    NONINFRINGEMENT. IN NO EVENT SHALL THE AUTHORS OR COPYRIGHT
 *    HOLDERS BE LIABLE FOR ANY CLAIM, DAMAGES OR OTHER LIABILITY,
 *    WHETHER IN AN ACTION OF CONTRACT, TORT OR OTHERWISE, ARISING
 *    FROM, OUT OF OR IN CONNECTION WITH THE SOFTWARE OR THE USE OR
 *    OTHER DEALINGS IN THE SOFTWARE.
 */


#include "LedControl.h"

//the opcodes for the MAX7221 and MAX7219
#define OP_NOOP   0
#define OP_DIGIT0 1
#define OP_DIGIT1 2
#define OP_DIGIT2 3
#define OP_DIGIT3 4
#define OP_DIGIT4 5
#define OP_DIGIT5 6
#define OP_DIGIT6 7
#define OP_DIGIT7 8
#define OP_DECODEMODE  9
#define OP_INTENSITY   10
#define OP_SCANLIMIT   11
#define OP_SHUTDOWN    12
#define OP_DISPLAYTEST 15

LedControl::LedControl(int dataPin, int clkPin, int csPin, int numDevices) {
    SPI_MOSI=dataPin;
    SPI_CLK=clkPin;
    SPI_CS=csPin;
    if(numDevices<=0 || numDevices>8 )
        numDevices=8;
    maxDevices=numDevices;
    pinMode(SPI_MOSI,OUTPUT);
    pinMode(SPI_CLK,OUTPUT);
    pinMode(SPI_CS,OUTPUT);
    digitalWrite(SPI_CS,HIGH);
    SPI_MOSI=dataPin;
    for(int i=0;i<64;i++) 
        status[i]=0x00;
    for(int i=0;i<maxDevices;i++) {
        spiTransfer(i,OP_DISPLAYTEST,0);
        //scanlimit is set to max on startup
        setScanLimit(i,7);
        //decode is done in source
        spiTransfer(i,OP_DECODEMODE,0);
        clearDisplay(i);
        //we go into shutdown-mode on startup
        shutdown(i,true);
    }
}

int LedControl::getDeviceCount() {
    return maxDevices;
}

void LedControl::shutdown(int addr, bool b) {
    if(addr<0 || addr>=maxDevices)
        return;
    if(b)
        spiTransfer(addr, OP_SHUTDOWN,0);
    else
        spiTransfer(addr, OP_SHUTDOWN,1);
}

void LedControl::setScanLimit(int addr, int limit) {
    if(addr<0 || addr>=maxDevices)
        return;
    if(limit>=0 && limit<8)
        spiTransfer(addr, OP_SCANLIMIT,limit);
}

void LedControl::setIntensity(int addr, int intensity) {
    if(addr<0 || addr>=maxDevices)
        return;
    if(intensity>=0 && intensity<16)	
        spiTransfer(addr, OP_INTENSITY,intensity);
}

void LedControl::clearDisplay(int addr) {
    int offset;

    if(addr<0 || addr>=maxDevices)
        return;
    offset=addr*8;
    for(int i=0;i<8;i++) {
        status[offset+i]=0;
        spiTransfer(addr, i+1,status[offset+i]);
    }
}

void LedControl::setLed(int addr, int row, int column, boolean state) {
    int offset;
    byte val=0x00;

    if(addr<0 || addr>=maxDevices)
        return;
    if(row<0 || row>7 || column<0 || column>7)
        return;
    offset=addr*8;
    val=B10000000 >> column;
    if(state)
        status[offset+row]=status[offset+row]|val;
    else {
        val=~val;
        status[offset+row]=status[offset+row]&val;
    }
    spiTransfer(addr, row+1,status[offset+row]);
}

void LedControl::setRow(int addr, int row, byte value) {
    int offset;
    if(addr<0 || addr>=maxDevices)
        return;
    if(row<0 || row>7)
        return;
    offset=addr*8;
    status[offset+row]=value;
    spiTransfer(addr, row+1,status[offset+row]);
}

void LedControl::setColumn(int addr, int col, byte value) {
    byte val;

    if(addr<0 || addr>=maxDevices)
        return;
    if(col<0 || col>7) 
        return;
    for(int row=0;row<8;row++) {
        val=value >> (7-row);
        val=val & 0x01;
        setLed(addr,row,col,val);
    }
}

void LedControl::setDigit(int addr, int digit, byte value, boolean dp) {
    int offset;
    byte v;

    if(addr<0 || addr>=maxDevices)
        return;
    if(digit<0 || digit>7 || value>15)
        return;
    offset=addr*8;
    v=pgm_read_byte_near(charTable + value); 
    if(dp)
        v|=B10000000;
    status[offset+digit]=v;
    spiTransfer(addr, digit+1,v);
}

void LedControl::setChar(int addr, int digit, char value, boolean dp) {
    int offset;
    byte index,v;

    if(addr<0 || addr>=maxDevices)
        return;
    if(digit<0 || digit>7)
        return;
    offset=addr*8;
    index=(byte)value;
    if(index >127) {
        //no defined beyond index 127, so we use the space char
        index=32;
    }
    v=pgm_read_byte_near(charTable + index); 
    if(dp)
        v|=B10000000;
    status[offset+digit]=v;
    spiTransfer(addr, digit+1,v);
}

void LedControl::spiTransfer(int addr, volatile byte opcode, volatile byte data) {
    //Create an array with the data to shift out
    int offset=addr*2;
    int maxbytes=maxDevices*2;

    for(int i=0;i<maxbytes;i++)
        spidata[i]=(byte)0;
    //put our device data into the array
    spidata[offset+1]=opcode;
    spidata[offset]=data;
    //enable the line 
    digitalWrite(SPI_CS,LOW);
    //Now shift out the data 
    for(int i=maxbytes;i>0;i--)
        shiftOut(SPI_MOSI,SPI_CLK,MSBFIRST,spidata[i-1]);
    //latch the data onto the display
    digitalWrite(SPI_CS,HIGH);
}    

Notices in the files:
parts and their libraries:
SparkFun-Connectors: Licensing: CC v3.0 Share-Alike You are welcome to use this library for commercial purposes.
